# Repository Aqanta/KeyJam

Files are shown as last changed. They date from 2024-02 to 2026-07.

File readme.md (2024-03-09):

# Aqanta KeyJam

The Aqanta KeyJam is a powerful opensource macro-pad that can be configured to send HID keystrokes, run complex macros on a connected computer, or be used as a drum-pad. 
The KeyJam runs on an RP2040 (Pico) board and can use a companion Electron app for control.

All code, designs, and methodology can be found in this repo. The project is unfinished and will be updated over time.

## Drums on Alpine Linux

APK installs:

fluidsynth

fluidsynth python driver is here, needs to be installed manually

https://github.com/nwhitehead/pyfluidsynth

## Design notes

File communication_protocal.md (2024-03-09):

## Serial Communication Protocol

This page describes how communication between the control app (Electron) and the KeyJam (RP2040 microcontroller) works.
All communication is done over the USB serial port and is primarily for setting key mappings.

>All serial commands are sent as text strings. No upper character limit has been observed.

### Definitions
* Keymapping
  * A map of what keys on the macropad press what keyboard keys or trigger macros
  * i.e. key 26 presses 'CONTROL + V'
* Profile
  * Set of keymappings
  * There are two levels of profiles, base and app
* Base Profile
  * This profile has mappings for all keys
  * One (and only one) must be applied at all times
* App Profile
  * Has mappings for some, but not all keys
  * Overrides base profile (where there is overlap)
  * Support for only 1 applied at a time (could be increased later)
* Keystroke
  * KeyJam sending an HID keyboard data stating a key is pressed
  * Three basic types: printing/non-printing, modifier, & consumer
  * Can be held down or pressed and released immediately
* Macro
  * A command to do something other than a keystroke
  * Almost always handled by the control software on the computer
  * i.e. key 13 sends a GET request to a URL

### Purposes & Functions
##### App to Device
* Set a keymapping (edit profile)
  * Per profile
  * Can be a keystroke or macro
* Create a profile
* Switch base profile
* Switch app profile
* Request profile data
##### Device to App
* Trigger macro

>These only take keystrokes into consideration. If built in, RGB lights will be controlled similarly

### Protocol
* All messages end with `\r\n`
  * A message is incrementally stored and not processed until `\r\n` is read
* Messages are send in a command line style, with parameters seperated by spaces and options set by flags
  * `list -c y -p base` tells the KeyJam to send the current base profile over serial
* Most responses to commands are given in JSON
#### Message structure
* Commands
  * Commands signify what action is to be taken. The following is an exhaustive list of commands:
  * App to Device
    * `update` - Updates a keymapping
    * `create` - Creates a new profile (non-destructive)
    * `list` - Returns a list of saved profiles, or the contents of a specified profile
  * Device to App
    * `press` - A macro key was pressed
* Flags
  * Flags are common across commands, though not every flag can be used in every command
    * `-p` - an profile (by id)
    * `-pt` - specifies profile type (can be `base` or `app`)
    * `-i` - the input number
    * `-j` - A JSON object (usually a key profile)
    * ~~`-it` - input type (`button`, `rotary`, etc.)~~

### Key JSON Format

```json
{
  "macro": false,
  "keys": ["a", 128],
  "consumerKey": 205,
  "hold": false
}
```

The `macro` boolean tells the controller if it should send the key press over the serial port.

The `keys` array lists all the keys that will send over via HID to the computer

The `consumerKey` integer contains a keycode for a consumer key

The `hold` boolean controls whether the keys are 'held down' or quickly presses and released.

All fields are optional, but it is encouraged to put a false value if there is no action to be taken.

### Profile JSON format

Each profile is an object with the following properties:

````json
{
  "id": "default",
  "displayName": "Default",
  "buttons": [],
  "rotaryEncoders": [],
  "potentiometers": []
}
````
Each button, rotary encoder, & potentiometer has a zero-based index associated with it. Each category has a list with a key (or key like object) in it.

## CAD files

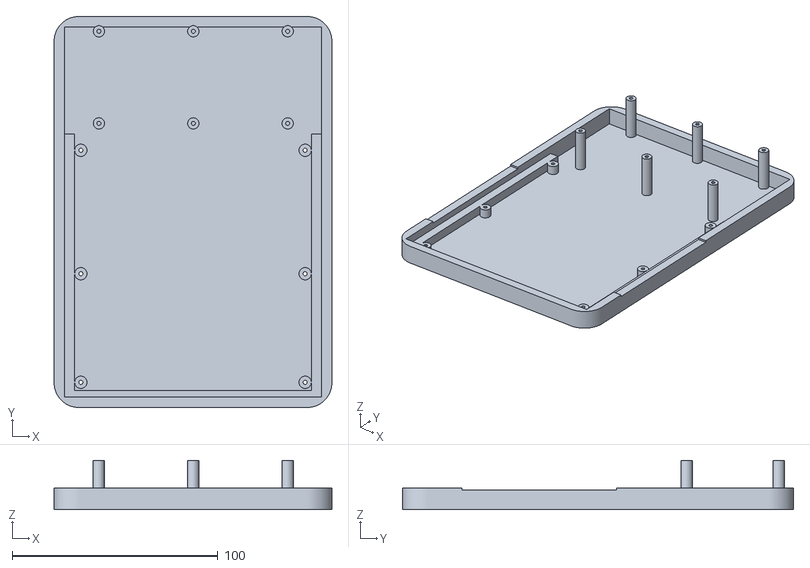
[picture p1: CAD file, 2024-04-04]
Design/3D Models/Frames/KeyJam Max Bottom.stl
135.0 x 190.0 x 24.0

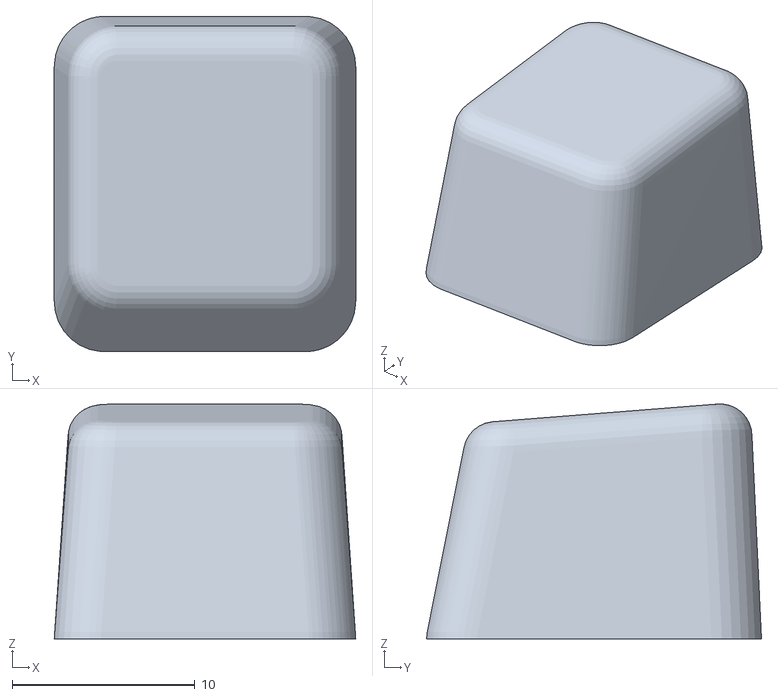
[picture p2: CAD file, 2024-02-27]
Design/3D Models/Keycap Prototypes/rounded_square_tall.stl
16.5 x 18.3 x 12.8

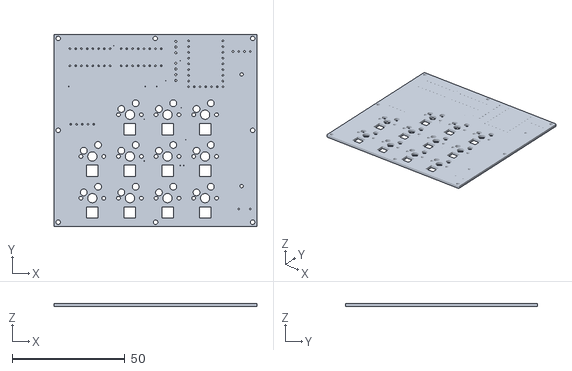
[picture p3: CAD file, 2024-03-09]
Design/3D Models/KeyJam PCB.stl
90.0 x 85.0 x 1.50

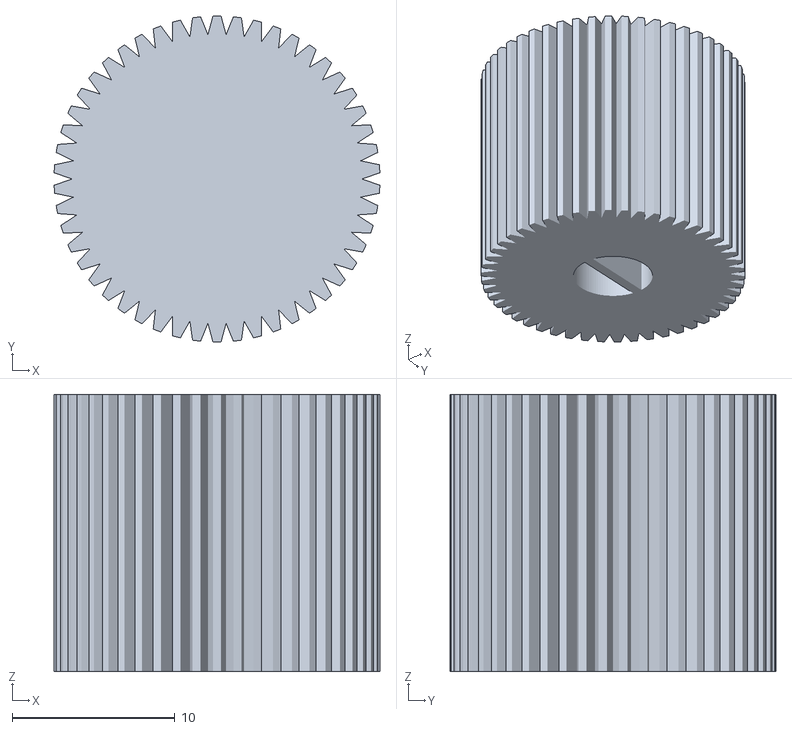
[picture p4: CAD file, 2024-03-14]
Design/3D Models/Knobs/Knob #1.stl
20.0 x 20.0 x 17.0

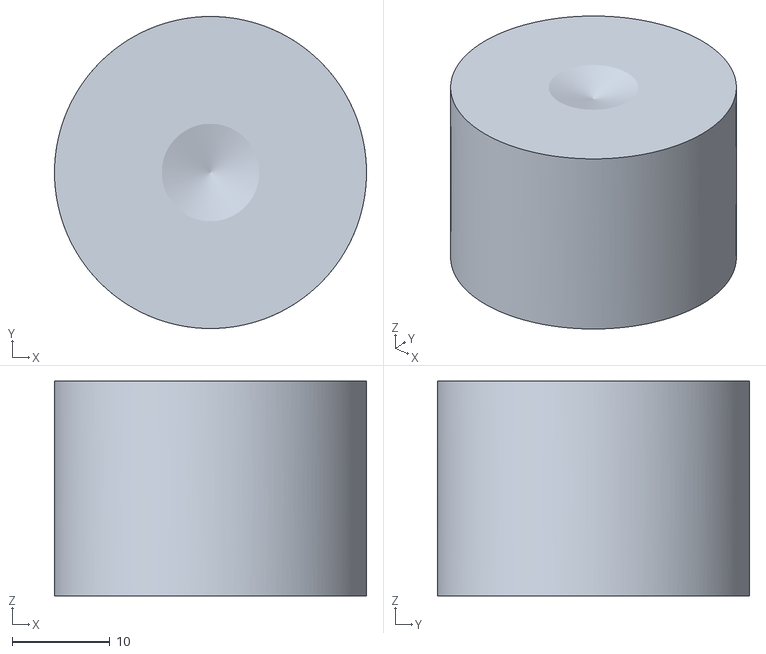
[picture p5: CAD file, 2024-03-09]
Design/3D Models/Knobs/v1/Knob #1.stl
32.0 x 32.0 x 22.0

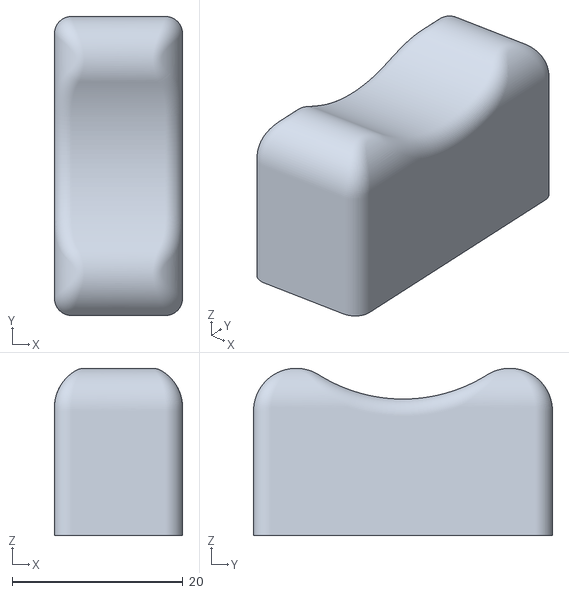
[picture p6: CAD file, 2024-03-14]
Design/3D Models/Sliders/Slider #3.stl
15.0 x 35.0 x 19.6

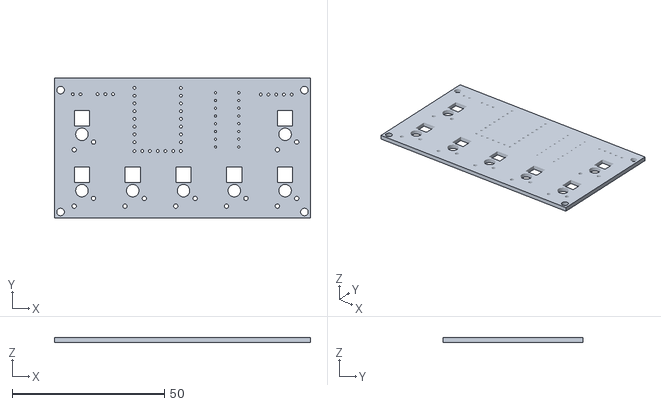
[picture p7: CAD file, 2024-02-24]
Design/3D Models/7 Key Prototype.stl
84.0 x 46.0 x 1.50

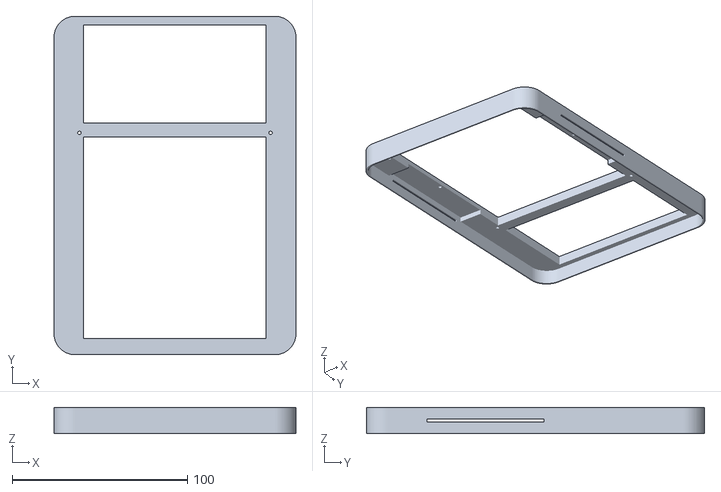
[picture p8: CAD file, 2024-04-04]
Design/3D Models/Frames/KeyJam Max Top.stl
138.0 x 193.0 x 15.0

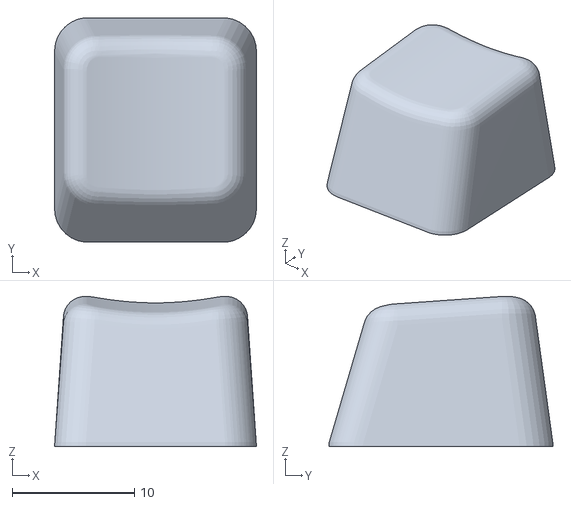
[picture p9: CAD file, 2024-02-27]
Design/3D Models/Keycap Prototypes/rounded_square_cylindrical.stl
16.5 x 18.3 x 12.3

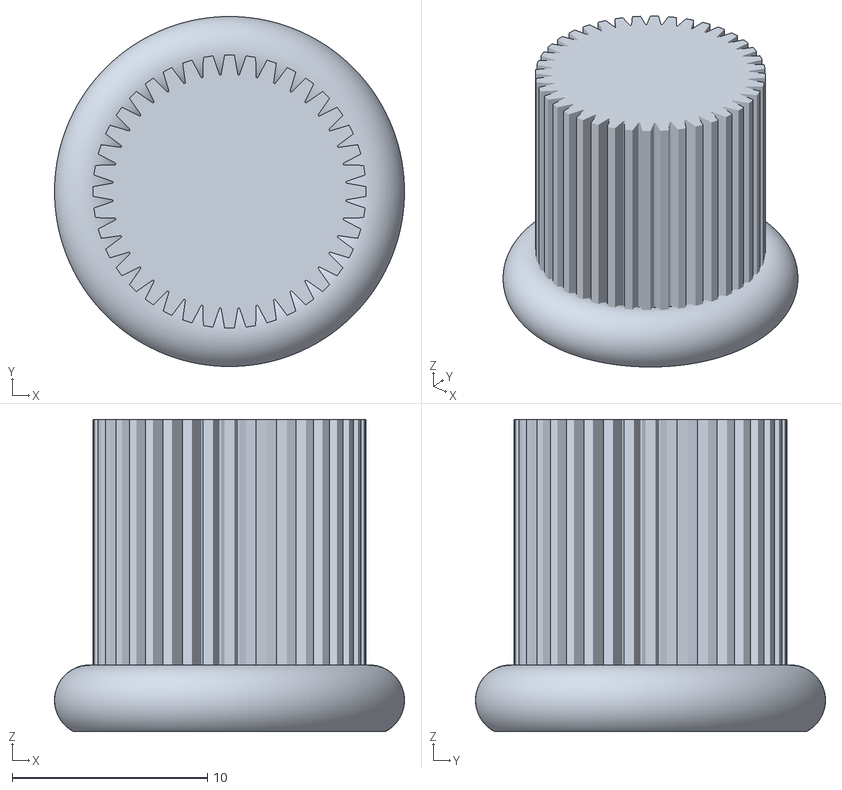
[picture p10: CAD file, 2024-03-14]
Design/3D Models/Knobs/Knob #5.stl
17.9 x 17.9 x 16.0

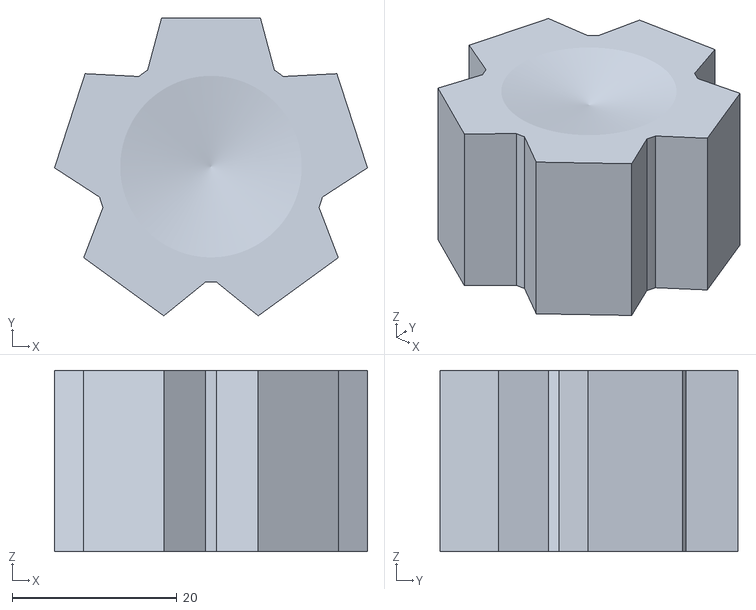
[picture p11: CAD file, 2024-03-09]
Design/3D Models/Knobs/v1/Knob #5.stl
37.9 x 36.1 x 22.0

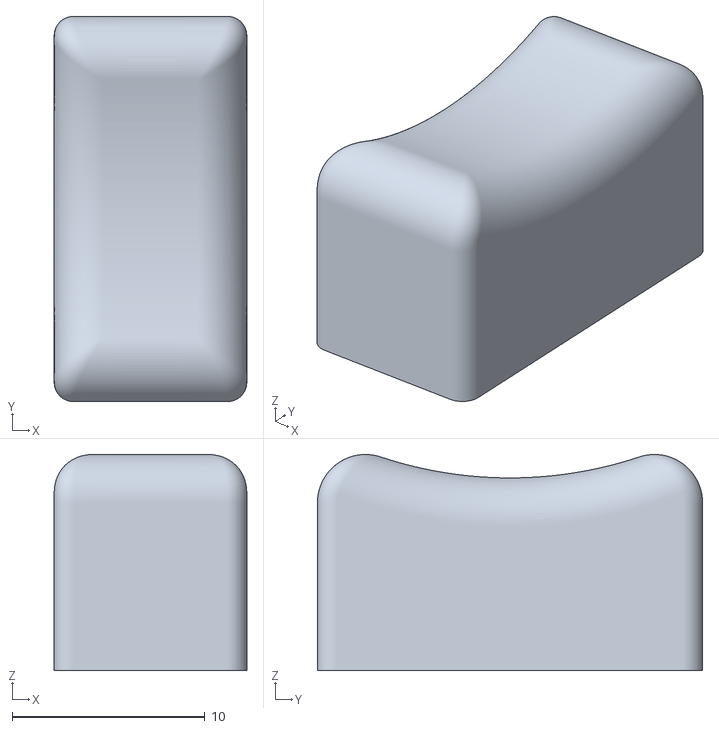
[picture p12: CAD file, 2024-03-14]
Design/3D Models/Sliders/Slider #2.stl
10.0 x 20.0 x 11.2

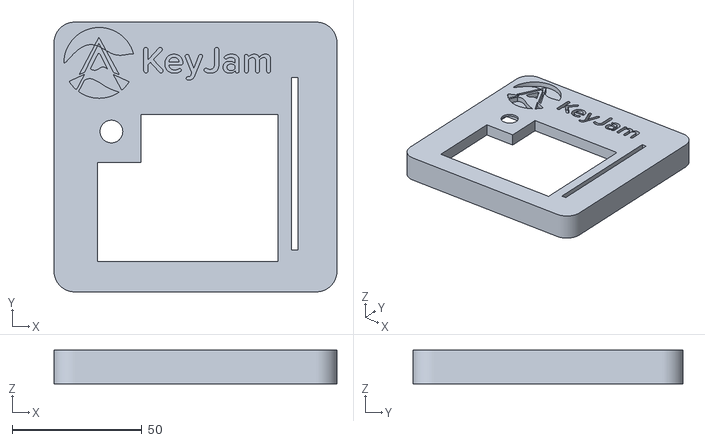
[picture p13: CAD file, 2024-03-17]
Design/3D Models/Frames/KeyJam Top.stl
109.1 x 104.0 x 13.0

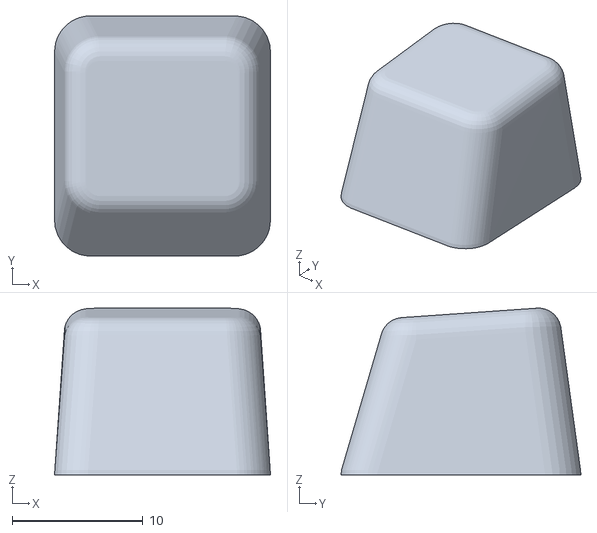
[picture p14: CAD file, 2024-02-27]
Design/3D Models/Keycap Prototypes/rounded_square.stl
16.5 x 18.3 x 12.7

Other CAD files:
Design/3D Models/Knobs/Knob #6.stl
Design/3D Models/Knobs/v1/Knob #6.stl
Design/3D Models/Sliders/Slider #1.stl
Design/3D Models/Frames/KeyJam Bottom.stl
Design/3D Models/Frames/KeyJam Housing.f3d
Design/3D Models/Frames/KeyJam Key Frame.stl
Design/3D Models/Frames/KeyJam Max Frame.stl
Design/3D Models/Frames/KeyJam Max Tippity-Top.stl
Design/3D Models/Keycap Prototypes/dsa_key.stl
Design/3D Models/Keycap Prototypes/flat_square.stl
Design/3D Models/Keycap Prototypes/g20_key.stl
Design/3D Models/Keycap Prototypes/square_dish.stl
Design/3D Models/Keycap Prototypes/square_key.stl
Design/3D Models/Knobs/Knob #2.stl
Design/3D Models/Knobs/Knob #3.stl
Design/3D Models/Knobs/Knob #4.stl
Design/3D Models/Knobs/v1/Knob #2.stl
Design/3D Models/Knobs/v1/Knob #3.stl
Design/3D Models/Knobs/v1/Knob #4.stl

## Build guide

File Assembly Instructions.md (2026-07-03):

# KeyJam Assembly Instructions

## Parts

### PCB

* KeyJam PCB
* 11x 10kΩ 1206 SMD Resistors
* 11x MK hotswap SMD sockets
* RP2040 Zero (with headers)
* 2x SN74HC165N shift registers
* 5 pin rotary encoder
* 10k linear potentiometer

### Case

* 3D printed parts:
  * Case bottom
  * Case frame/middle
  * Case top
  * 11x keycaps
  * Rotary encoder cap
  * Slider cap
* 11x MX switches
* 4x m2x16 screws
* 4x Clear self-adhesive rubber feet

## Assembly

### PCB - Bottom Side

The first step is to solder the SMD components on the bottom of the board. **Using a heat gun or hot plate is highly recommended for this step.** You will need the 11 smd resistors, and 11 hotswap sockets. 

Place solder on all the flat SMD (no holes in them) pads on the back of the PCB (the side that says "KeyJam" with the big logo on it). Place the 11 resistors in a line near the top, and insert the hotswap sockets into the holes. Make sure both metal tabs are over the SMD pads, and that they poke through the holes. Then use the heatgun or hotplate to solder. 

Double check all the joins to make sure they are flat and have contact with the metal.

*You can solder the hotpads conventionally, but start with SMD. Add more wire solder as needed if they fall out*

### PCB - Top Side

Place the rest of the components on the PCB:

* The RP2040 Zero goes above the RP2040 logo
* The SN74HC165Ns go in the SR_1 and SR_2 spots, make sure to match the notch
* The slider/potentiometer holes are off center, you will need to bend the pins to fit it in.
* Place the frame over the top of the PCB, then solder the rotary encoder in.

> I recommend using a wedge tip and 0.6mm 60/40 tin/lead solder

### Case

1. Place the PCB (with frame) into the bottom of the case, it should slot in
2. Place the top on
3. Use at least 4 screws in the screw holes at the bottom of the case to screw the stack together.
4. Place the MX switched into the frame
5. Place the keycaps and handles.

## Programming

Clone the git repo and use PlatformIO to flash.

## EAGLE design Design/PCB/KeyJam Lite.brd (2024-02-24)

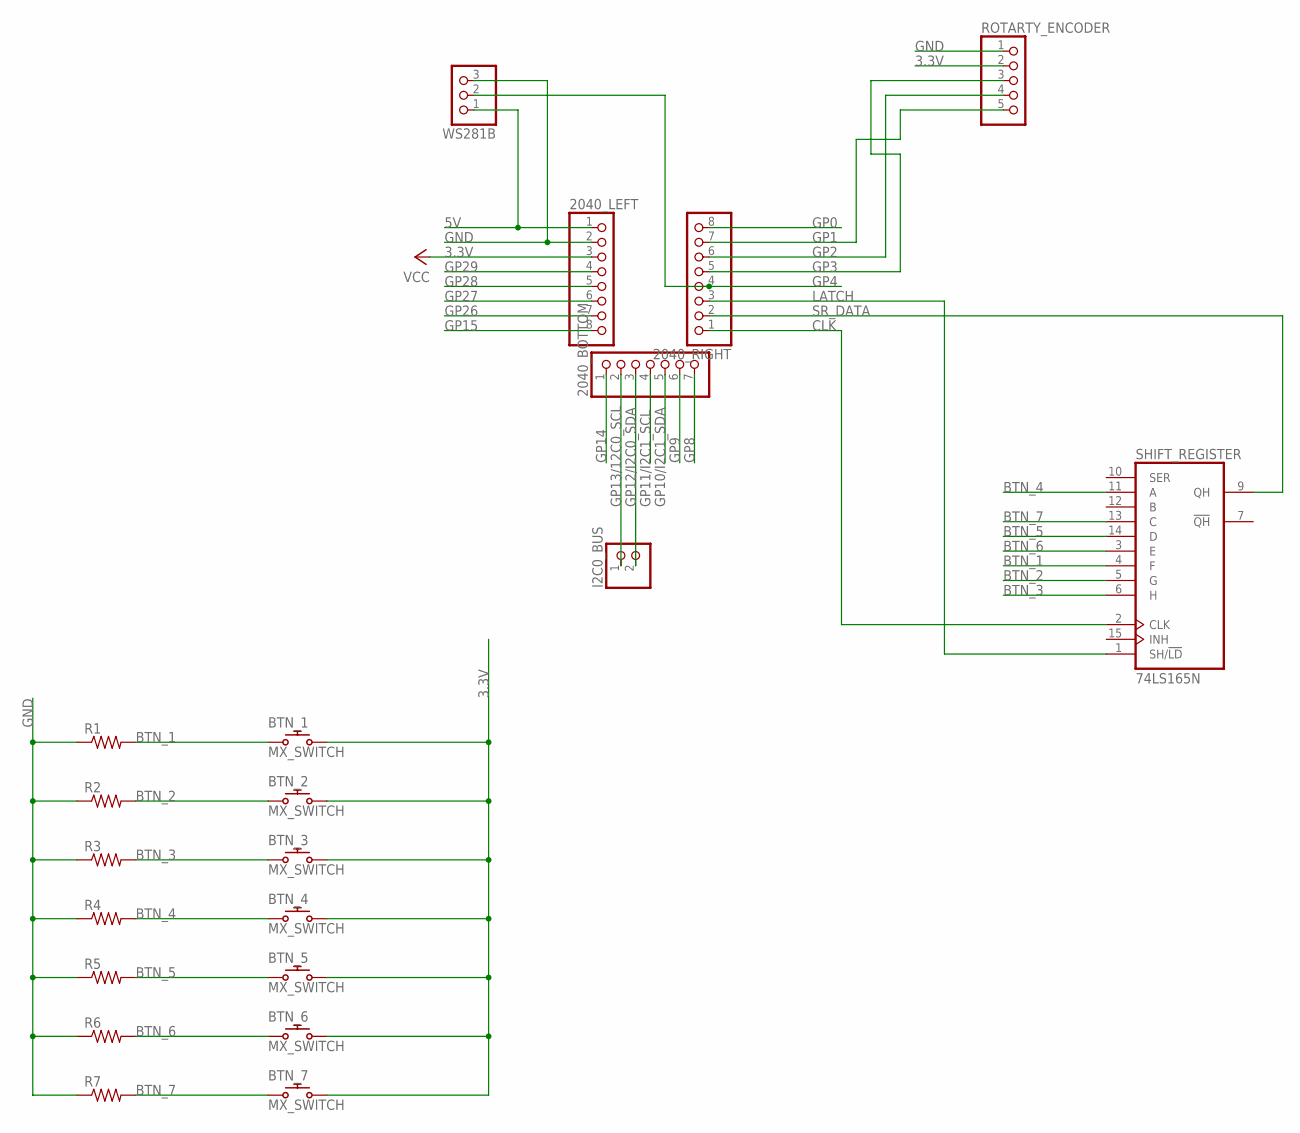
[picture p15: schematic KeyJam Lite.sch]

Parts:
2040_BOTTOM: PINHD-1X7; 1X07
2040_LEFT, 2040_RIGHT: PINHD-1X8; 1X08
BTN_1, BTN_2, BTN_3, BTN_4, BTN_5, BTN_6, BTN_7: MX_SWITCH
I2C0_BUS: PINHD-1X2; 1X02
R1, R2, R3, R4, R5, R6, R7: ADAFRUIT_R-US_R0805; ADAFRUIT_R0805
ROTARTY_ENCODER: PINHD-1X5; 1X05
SHIFT_REGISTER: 74LS165N; DIL16
WS281B: PINHD-1X3; 1X03

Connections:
3.3V: 2040_LEFT.3, BTN_1.S2 (2), BTN_2.S2 (2), BTN_3.S2 (2), BTN_4.S2 (2), BTN_5.S2 (2), BTN_6.S2 (2), BTN_7.S2 (2), ROTARTY_ENCODER.2, SHIFT_REGISTER.16 (VCC)
5V: 2040_LEFT.1, WS281B.1
BTN_1: BTN_1.S1 (1), R1.2, SHIFT_REGISTER.4 (F)
BTN_2: BTN_2.S1 (1), R2.2, SHIFT_REGISTER.5 (G)
BTN_3: BTN_3.S1 (1), R3.2, SHIFT_REGISTER.6 (H)
BTN_4: BTN_4.S1 (1), R4.2, SHIFT_REGISTER.11 (A)
BTN_5: BTN_5.S1 (1), R5.2, SHIFT_REGISTER.14 (D)
BTN_6: BTN_6.S1 (1), R6.2, SHIFT_REGISTER.3 (E)
BTN_7: BTN_7.S1 (1), R7.2, SHIFT_REGISTER.13 (C)
CLK: 2040_RIGHT.1, SHIFT_REGISTER.2 (CLK)
GND: 2040_LEFT.2, R1.1, R2.1, R3.1, R4.1, R5.1, R6.1, R7.1, ROTARTY_ENCODER.1, SHIFT_REGISTER.8 (GND), WS281B.3
GP0: 2040_RIGHT.8
GP1: 2040_RIGHT.7, ROTARTY_ENCODER.5
GP2: 2040_RIGHT.6, ROTARTY_ENCODER.4
GP3: 2040_RIGHT.5, ROTARTY_ENCODER.3
GP4: 2040_RIGHT.4, WS281B.2
GP8: 2040_BOTTOM.7
GP9: 2040_BOTTOM.6
GP10/I2C1_SDA: 2040_BOTTOM.5
GP11/I2C1_SCL: 2040_BOTTOM.4
GP12/I2C0_SDA: 2040_BOTTOM.3, I2C0_BUS.2
GP13/12C0_SCL: 2040_BOTTOM.2, I2C0_BUS.1
GP14: 2040_BOTTOM.1
GP15: 2040_LEFT.8
GP26: 2040_LEFT.7
GP27: 2040_LEFT.6
GP28: 2040_LEFT.5
GP29: 2040_LEFT.4
LATCH: 2040_RIGHT.3, SHIFT_REGISTER.1 (SH/!LD)
SR_DATA: 2040_RIGHT.2, SHIFT_REGISTER.9 (QH)

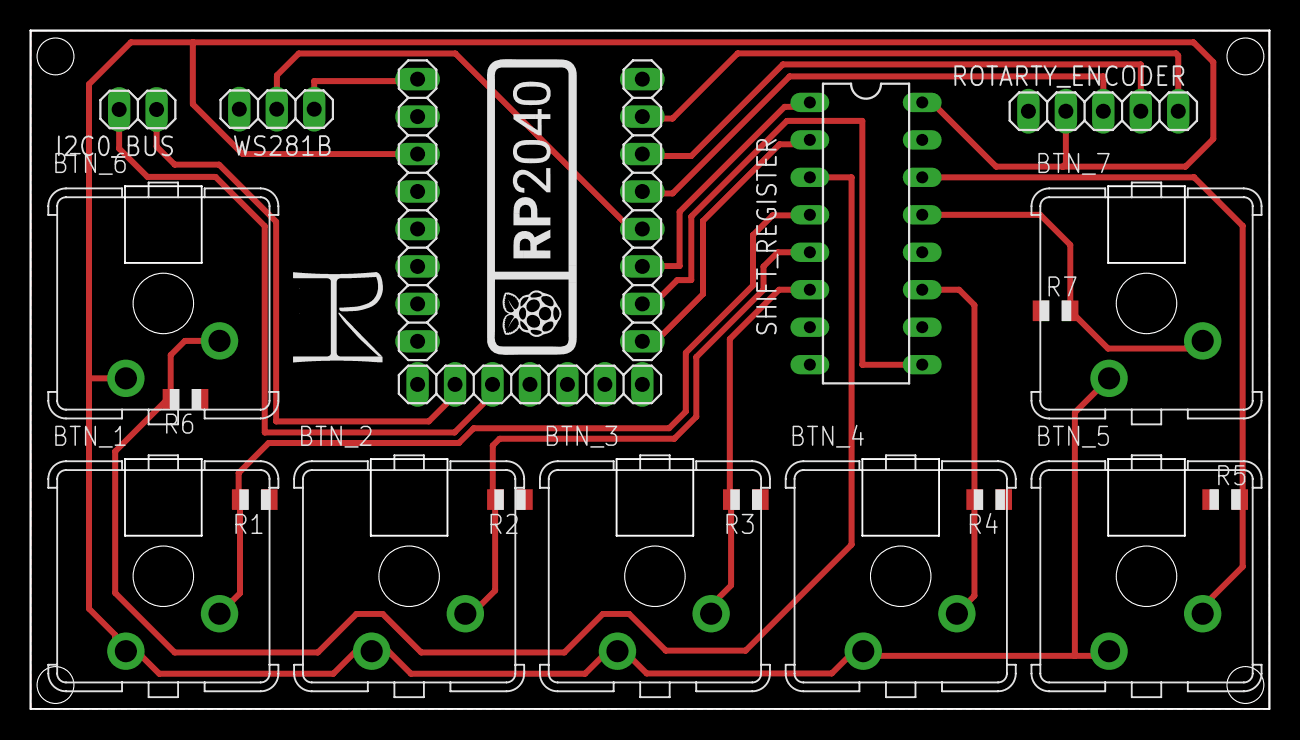
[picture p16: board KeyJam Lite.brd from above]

Board: 2 copper layers, 84.0 x 46.0 mm, 22 parts (0 on the bottom side), 19 nets.

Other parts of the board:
U$1: RASPI_RP2040_LOGO_20MM

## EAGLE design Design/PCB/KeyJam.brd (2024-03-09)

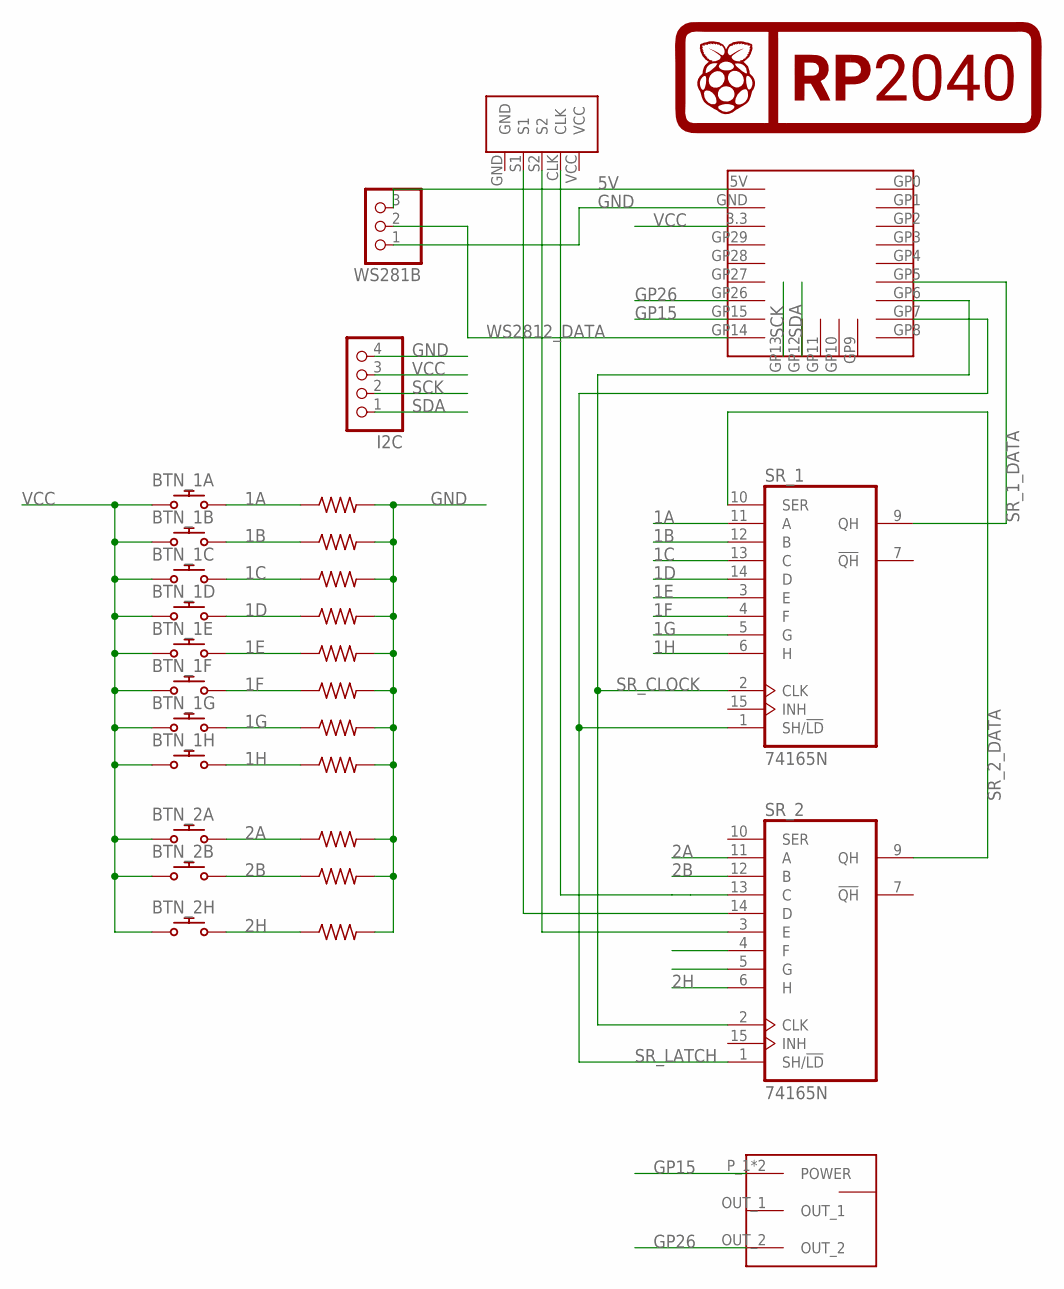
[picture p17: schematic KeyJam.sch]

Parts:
BTN_1A, BTN_1B, BTN_1C, BTN_1D, BTN_1E, BTN_1F, BTN_1G, BTN_1H, BTN_2A, BTN_2B, BTN_2H: MX_SWITCH
I2C: PINHD-1X4; 1X04
R1, R2, R3, R4, R5, R6, R7, R8, R9, R10, R11: R-US_R1206; R1206
SLIDER: SLIDER
SR_1, SR_2: 74165N; DIL16
U$1: RP2040-ZERO
U$2: ROUND_ROTARY
U$3: RASPI_RP2040_LOGO_20MM
WS281B: PINHD-1X3; 1X03

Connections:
1A: BTN_1A.$2 (2), R1.1, SR_1.11 (A)
1B: BTN_1B.$2 (2), R2.1, SR_1.12 (B)
1C: BTN_1C.$2 (2), R3.1, SR_1.13 (C)
1D: BTN_1D.$2 (2), R4.1, SR_1.14 (D)
1E: BTN_1E.$2 (2), R5.1, SR_1.3 (E)
1F: BTN_1F.$2 (2), R6.1, SR_1.4 (F)
1G: BTN_1G.$2 (2), R7.1, SR_1.5 (G)
1H: BTN_1H.$2 (2), R8.1, SR_1.6 (H)
2A: BTN_2A.$2 (2), R9.1, SR_2.11 (A)
2B: BTN_2B.$2 (2), R10.1, SR_2.12 (B)
2H: BTN_2H.$2 (2), R11.1, SR_2.6 (H)
5V: U$1.5V (5), WS281B.3
GND: I2C.4, R1.2, R2.2, R3.2, R4.2, R5.2, R6.2, R7.2, R8.2, R9.2, R10.2, R11.2, SLIDER.GND_1 (GND), SLIDER.GND_2 (GND), SR_1.8 (GND), SR_2.8 (GND), U$1.GND, U$2.GND, WS281B.1
GP15: SLIDER.P_1 (POWER), SLIDER.P_2 (POWER), U$1.GP15
GP26: SLIDER.OUT_2, U$1.GP26
unnamed: SR_2.13 (C), U$2.CLK
unnamed: SR_2.14 (D), U$2.S1
unnamed: SR_2.3 (E), U$2.S2
SCK: I2C.2, U$1.GP13
SDA: I2C.1, U$1.GP12
SR_1_DATA: SR_1.9 (QH), U$1.GP5
SR_2_DATA: SR_1.10 (SER), SR_2.9 (QH)
SR_CLOCK: SR_1.2 (CLK), SR_2.2 (CLK), U$1.GP6
SR_LATCH: SR_1.1 (SH/!LD), SR_2.1 (SH/!LD), U$1.GP7
VCC: BTN_1A.$1 (1), BTN_1B.$1 (1), BTN_1C.$1 (1), BTN_1D.$1 (1), BTN_1E.$1 (1), BTN_1F.$1 (1), BTN_1G.$1 (1), BTN_1H.$1 (1), BTN_2A.$1 (1), BTN_2B.$1 (1), BTN_2H.$1 (1), I2C.3, SR_1.16 (VCC), SR_2.16 (VCC), U$1.3.3, U$2.VCC
WS2812_DATA: U$1.GP14, WS281B.2

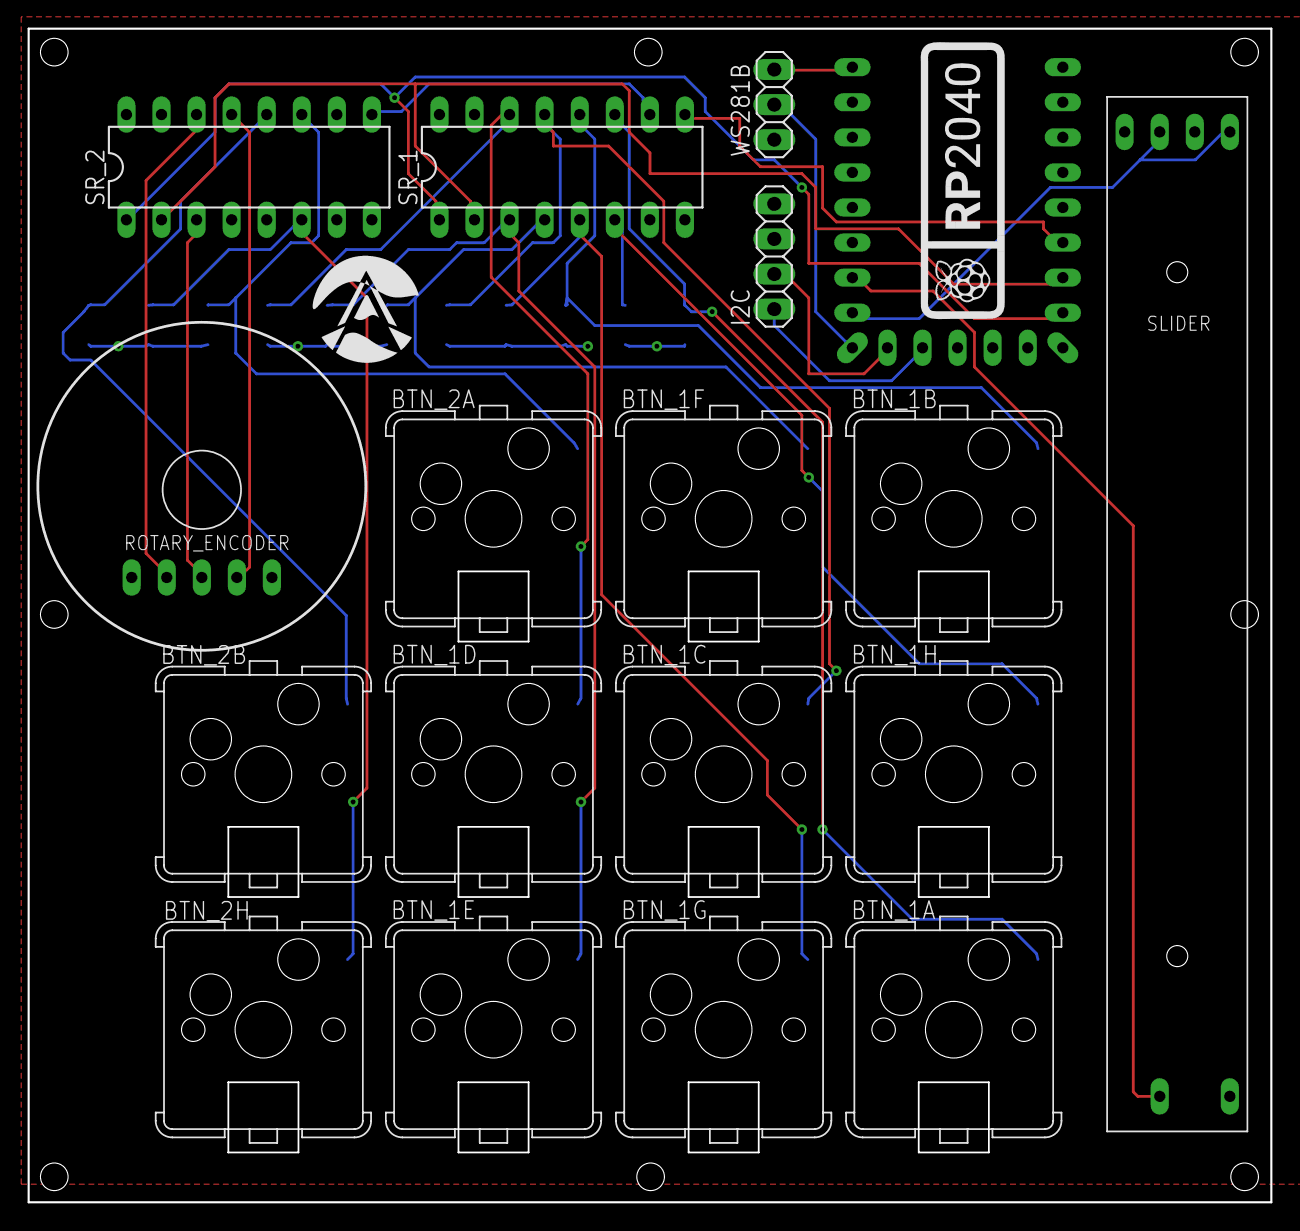
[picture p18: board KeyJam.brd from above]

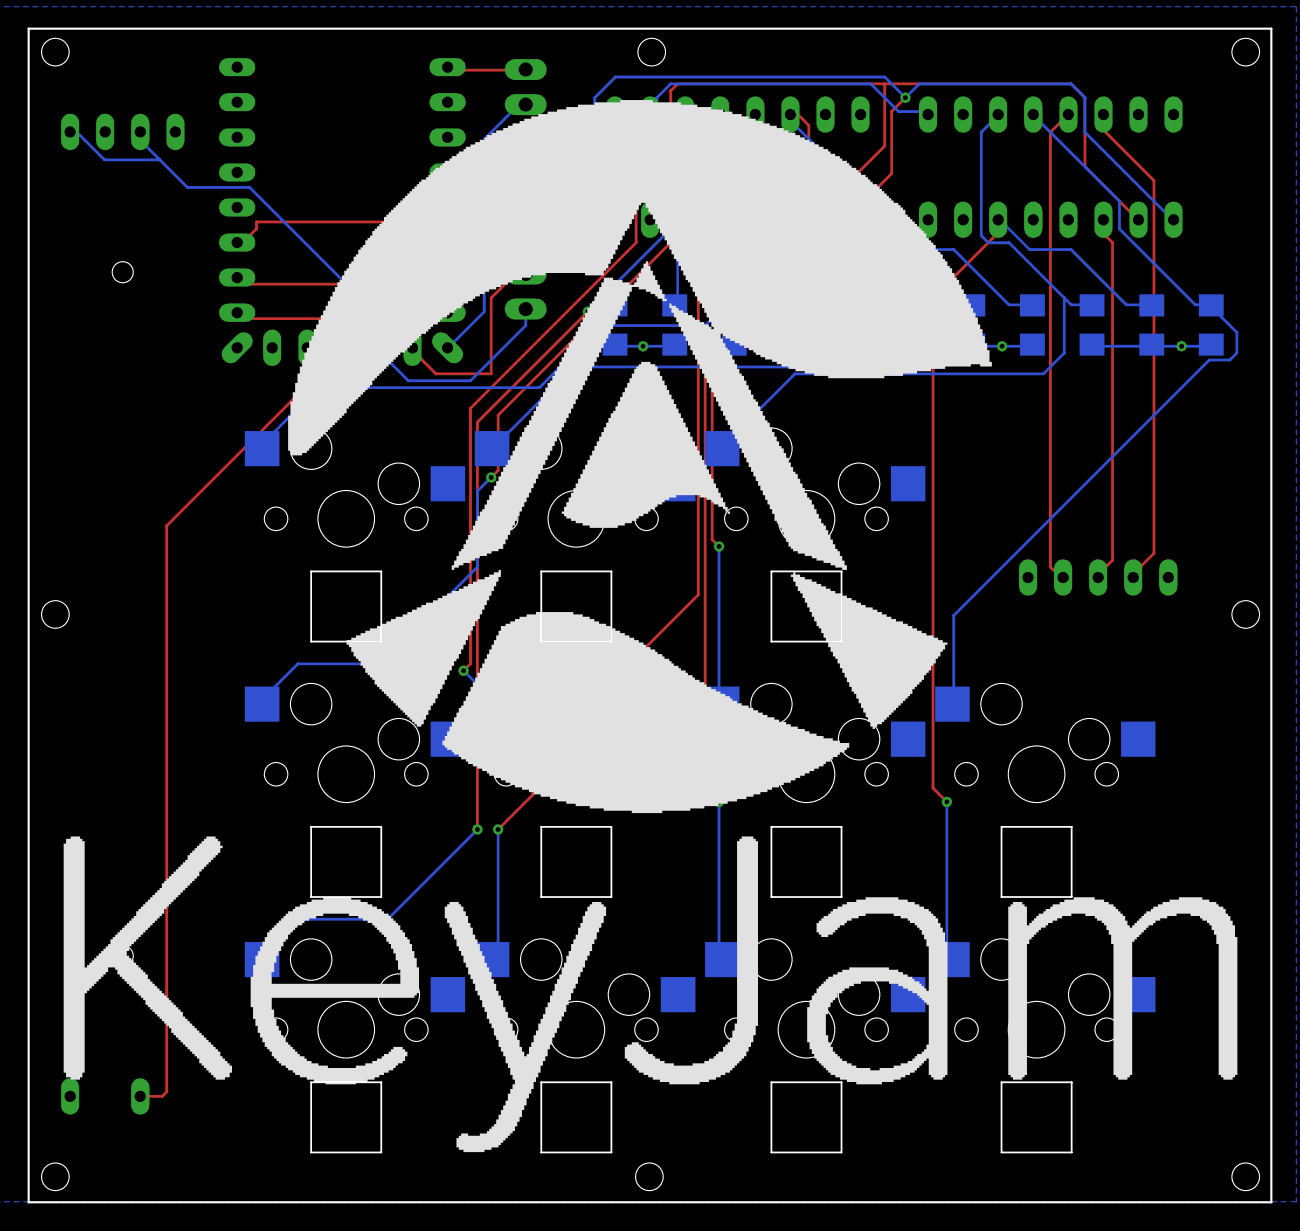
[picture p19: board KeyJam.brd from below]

Board: 2 copper layers, 90.0 x 85.0 mm, 30 parts (11 on the bottom side), 26 nets.

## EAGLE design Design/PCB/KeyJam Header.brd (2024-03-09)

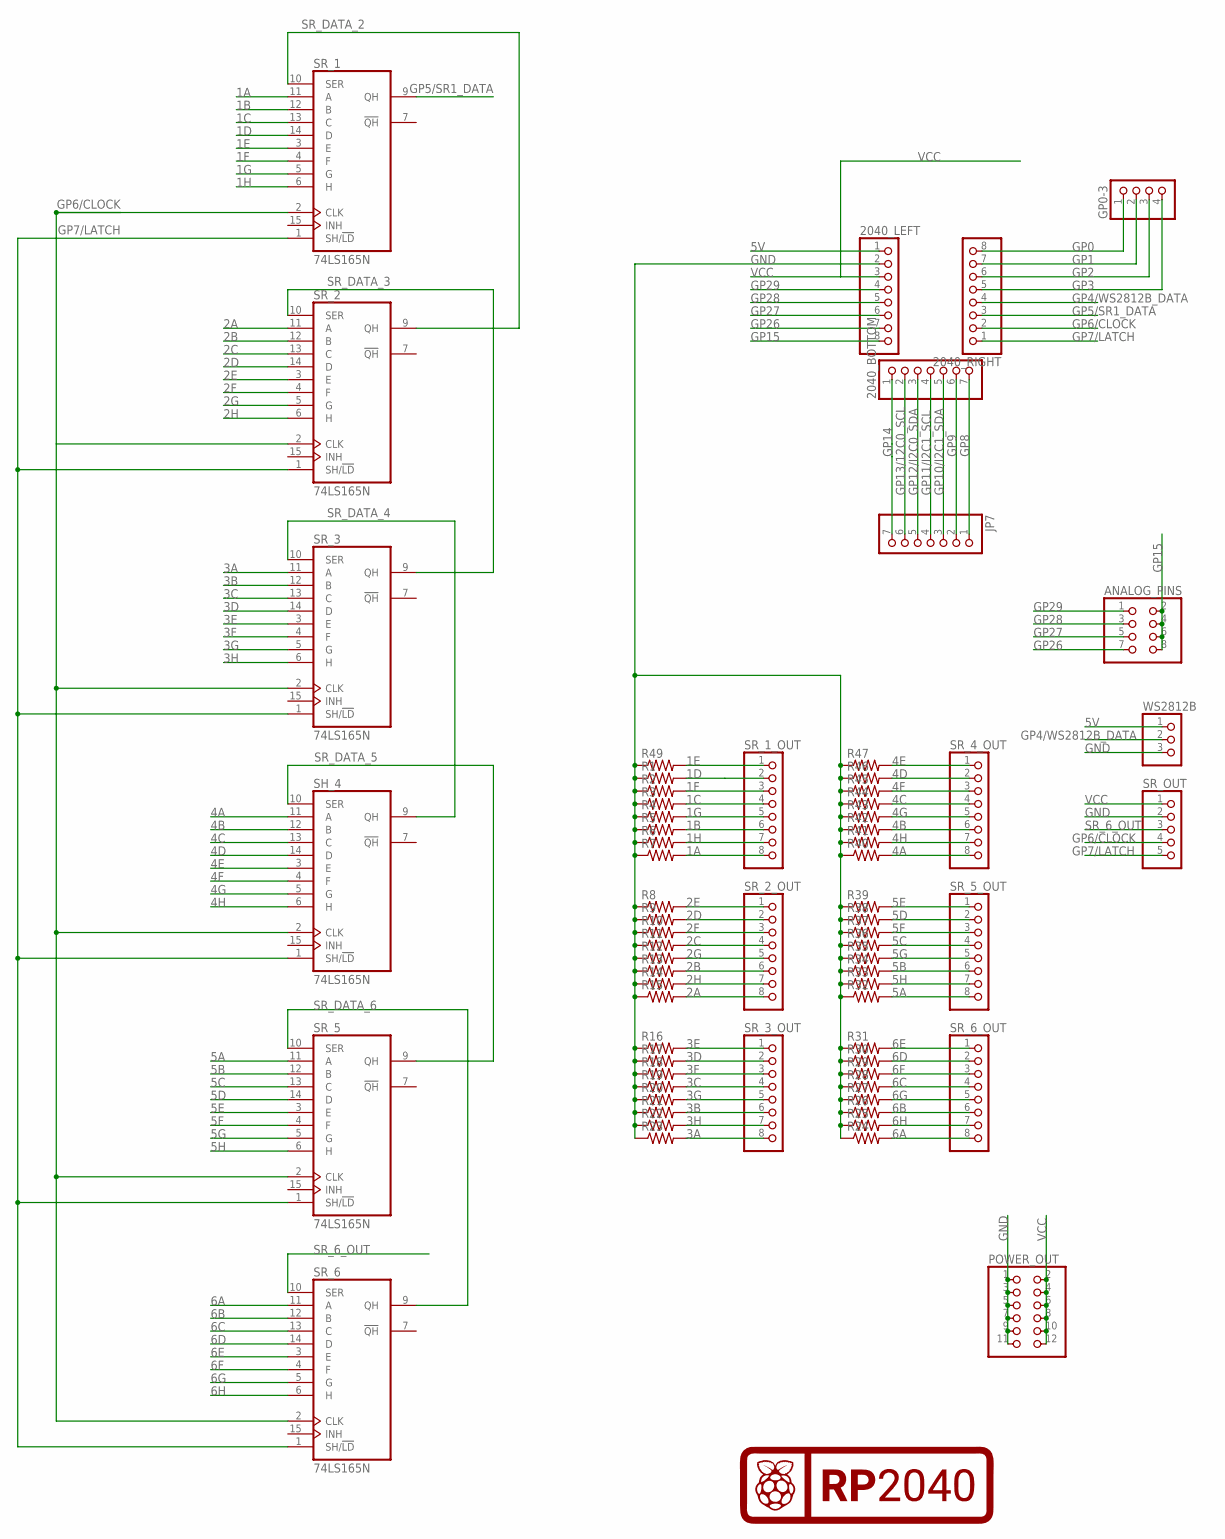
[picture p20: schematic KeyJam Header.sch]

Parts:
2040_BOTTOM: PINHD-1X7; 1X07
2040_LEFT, 2040_RIGHT: PINHD-1X8; 1X08
ANALOG_PINS: PINHD-2X4; 2X04
GP0-3: PINHD-1X4; 1X04
JP7: PINHD-1X7; 1X07
POWER_OUT: PINHD-2X6; 2X06
R1, R2, R3, R4, R5, R6, R7, R8, R9, R10, R11, R12, R13, R14, R15, R16, R17, R18, R19, R20, R21, R22, R23, R24, R25, R26, R27, R28, R29, R30, R31, R32, R33, R34, R35, R36, R37, R38, R39, R40, R41, R42, R43, R44, R45, R46, R47, R49: R-US_R1206; R1206
SH_4: 74LS165N; DIL16
SR_1, SR_2, SR_3, SR_5, SR_6: 74LS165N; DIL16
SR_1_OUT, SR_2_OUT, SR_3_OUT, SR_4_OUT, SR_5_OUT, SR_6_OUT: PINHD-1X8; 1X08
SR_OUT: PINHD-1X5; 1X05
U$1: RASPI_RP2040_LOGO_20MM
WS2812B: PINHD-1X3; 1X03

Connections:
1A: R7.2, SR_1.11 (A), SR_1_OUT.8
1B: R5.2, SR_1.12 (B), SR_1_OUT.6
1C: R3.2, SR_1.13 (C), SR_1_OUT.4
1D: R1.2, SR_1.14 (D), SR_1_OUT.2
1E: R49.2, SR_1.3 (E), SR_1_OUT.1
1F: R2.2, SR_1.4 (F), SR_1_OUT.3
1G: R4.2, SR_1.5 (G), SR_1_OUT.5
1H: R6.2, SR_1.6 (H), SR_1_OUT.7
2A: R15.2, SR_2.11 (A), SR_2_OUT.8
2B: R13.2, SR_2.12 (B), SR_2_OUT.6
2C: R11.2, SR_2.13 (C), SR_2_OUT.4
2D: R9.2, SR_2.14 (D), SR_2_OUT.2
2E: R8.2, SR_2.3 (E), SR_2_OUT.1
2F: R10.2, SR_2.4 (F), SR_2_OUT.3
2G: R12.2, SR_2.5 (G), SR_2_OUT.5
2H: R14.2, SR_2.6 (H), SR_2_OUT.7
3A: R23.2, SR_3.11 (A), SR_3_OUT.8
3B: R21.2, SR_3.12 (B), SR_3_OUT.6
3C: R19.2, SR_3.13 (C), SR_3_OUT.4
3D: R17.2, SR_3.14 (D), SR_3_OUT.2
3E: R16.2, SR_3.3 (E), SR_3_OUT.1
3F: R18.2, SR_3.4 (F), SR_3_OUT.3
3G: R20.2, SR_3.5 (G), SR_3_OUT.5
3H: R22.2, SR_3.6 (H), SR_3_OUT.7
4A: R40.2, SH_4.11 (A), SR_4_OUT.8
4B: R42.2, SH_4.12 (B), SR_4_OUT.6
4C: R44.2, SH_4.13 (C), SR_4_OUT.4
4D: R46.2, SH_4.14 (D), SR_4_OUT.2
4E: R47.2, SH_4.3 (E), SR_4_OUT.1
4F: R45.2, SH_4.4 (F), SR_4_OUT.3
4G: R43.2, SH_4.5 (G), SR_4_OUT.5
4H: R41.2, SH_4.6 (H), SR_4_OUT.7
5A: R32.2, SR_5.11 (A), SR_5_OUT.8
5B: R34.2, SR_5.12 (B), SR_5_OUT.6
5C: R36.2, SR_5.13 (C), SR_5_OUT.4
5D: R38.2, SR_5.14 (D), SR_5_OUT.2
5E: R39.2, SR_5.3 (E), SR_5_OUT.1
5F: R37.2, SR_5.4 (F), SR_5_OUT.3
5G: R35.2, SR_5.5 (G), SR_5_OUT.5
5H: R33.2, SR_5.6 (H), SR_5_OUT.7
5V: 2040_LEFT.1, WS2812B.1
6A: R24.2, SR_6.11 (A), SR_6_OUT.8
6B: R26.2, SR_6.12 (B), SR_6_OUT.6
6C: R28.2, SR_6.13 (C), SR_6_OUT.4
6D: R30.2, SR_6.14 (D), SR_6_OUT.2
6E: R31.2, SR_6.3 (E), SR_6_OUT.1
6F: R29.2, SR_6.4 (F), SR_6_OUT.3
6G: R27.2, SR_6.5 (G), SR_6_OUT.5
6H: R25.2, SR_6.6 (H), SR_6_OUT.7
GND: 2040_LEFT.2, POWER_OUT.1, POWER_OUT.3, POWER_OUT.5, POWER_OUT.7, POWER_OUT.9, POWER_OUT.11, R1.1, R2.1, R3.1, R4.1, R5.1, R6.1, R7.1, R8.1, R9.1, R10.1, R11.1, R12.1, R13.1, R14.1, R15.1, R16.1, R17.1, R18.1, R19.1, R20.1, R21.1, R22.1, R23.1, R24.1, R25.1, R26.1, R27.1, R28.1, R29.1, R30.1, R31.1, R32.1, R33.1, R34.1, R35.1, R36.1, R37.1, R38.1, R39.1, R40.1, R41.1, R42.1, R43.1, R44.1, R45.1, R46.1, R47.1, R49.1, SH_4.8 (GND), SR_1.8 (GND), SR_2.8 (GND), SR_3.8 (GND), SR_5.8 (GND), SR_6.8 (GND), SR_OUT.2, WS2812B.3
GP0: 2040_RIGHT.8, GP0-3.1
GP1: 2040_RIGHT.7, GP0-3.2
GP2: 2040_RIGHT.6, GP0-3.3
GP3: 2040_RIGHT.5, GP0-3.4
GP4/WS2812B_DATA: 2040_RIGHT.4, WS2812B.2
GP5/SR1_DATA: 2040_RIGHT.3, SR_1.9 (QH)
GP6/CLOCK: 2040_RIGHT.2, SH_4.2 (CLK), SR_1.2 (CLK), SR_2.2 (CLK), SR_3.2 (CLK), SR_5.2 (CLK), SR_6.2 (CLK), SR_OUT.4
GP7/LATCH: 2040_RIGHT.1, SH_4.1 (SH/!LD), SR_1.1 (SH/!LD), SR_2.1 (SH/!LD), SR_3.1 (SH/!LD), SR_5.1 (SH/!LD), SR_6.1 (SH/!LD), SR_OUT.5
GP8: 2040_BOTTOM.7, JP7.1
GP9: 2040_BOTTOM.6, JP7.2
GP10/I2C1_SDA: 2040_BOTTOM.5, JP7.3
GP11/I2C1_SCL: 2040_BOTTOM.4, JP7.4
GP12/I2C0_SDA: 2040_BOTTOM.3, JP7.5
GP13/12C0_SCL: 2040_BOTTOM.2, JP7.6
GP14: 2040_BOTTOM.1, JP7.7
GP15: 2040_LEFT.8, ANALOG_PINS.2, ANALOG_PINS.4, ANALOG_PINS.6, ANALOG_PINS.8
GP26: 2040_LEFT.7, ANALOG_PINS.7
GP27: 2040_LEFT.6, ANALOG_PINS.5
GP28: 2040_LEFT.5, ANALOG_PINS.3
GP29: 2040_LEFT.4, ANALOG_PINS.1
SR_6_OUT: SR_6.10 (SER), SR_OUT.3
SR_DATA_2: SR_1.10 (SER), SR_2.9 (QH)
SR_DATA_3: SR_2.10 (SER), SR_3.9 (QH)
SR_DATA_4: SH_4.9 (QH), SR_3.10 (SER)
SR_DATA_5: SH_4.10 (SER), SR_5.9 (QH)
SR_DATA_6: SR_5.10 (SER), SR_6.9 (QH)
VCC: 2040_LEFT.3, POWER_OUT.2, POWER_OUT.4, POWER_OUT.6, POWER_OUT.8, POWER_OUT.10, POWER_OUT.12, SH_4.16 (VCC), SR_1.16 (VCC), SR_2.16 (VCC), SR_3.16 (VCC), SR_5.16 (VCC), SR_6.16 (VCC), SR_OUT.1

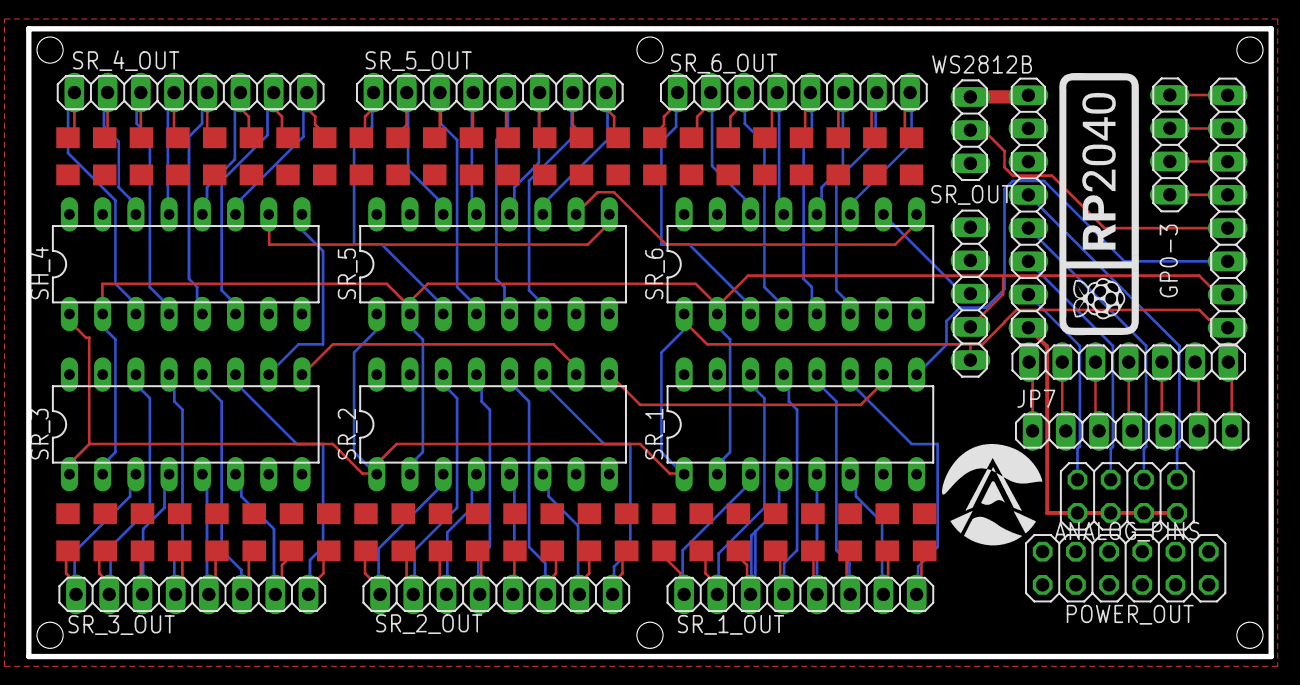
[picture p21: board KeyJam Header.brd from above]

Board: 2 copper layers, 95.0 x 48.0 mm, 70 parts (0 on the bottom side), 77 nets.

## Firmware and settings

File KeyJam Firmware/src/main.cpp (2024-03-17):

#include <Arduino.h>
#include <nlohmann/json.hpp>
#include <Keyboard.h>
#include <LittleFS.h>
#include <sstream>
#include <set>
#include <deque>

//define pins here
#define DATA 5
#define LATCH 7
#define CLOCK 6
//define number of buttons
#define BTN_N 16
//should we re-write the config
#define NEW_CONFIG false

//include other project files
#include "config.h"
#include "serialControl.h"
#include "shiftRegister.h"

//setup json and config
using json = nlohmann::json;
using namespace nlohmann::literals;
json currentBaseConfig;
json currentProfileConfig;

//input/button variables
std::vector<int> inputs( BTN_N );
std::vector<int> rawInputs( BTN_N );
std::vector<int> previousInputs( BTN_N );

//encoder variables
std::set<int> encoderInputs;

//slider variables
std::deque<int> sliderPin1;
std::deque<int> sliderPin2;
int sliderLevel;
int sliderPreviousLevel = -100;

//set up serial
SerialControl serialControl = SerialControl();

//set up shift register
ShiftRegister buttonRegister = ShiftRegister( DATA, CLOCK, LATCH, BTN_N );

//helper function to find the index on a vector
int getIndex( std::vector<std::string> v, const std::string &K ) {
    auto it = find( v.begin(), v.end(), K );
    if ( it != v.end()) {
        return it - v.begin();
    } else {
        return -1;
    }
}

void setup() {
    //If the config file does not exit, create it
    if ( LittleFS.begin() && (!LittleFS.exists( "/config.json" ) || NEW_CONFIG)) {
        initializeConfigFile();
    }

    //load in basic config
    File configFile = LittleFS.open( "/config.json", "r" );
    currentBaseConfig = json::parse( configFile.readString());
    configFile.close();

    //initialize the keyboard
    Keyboard.begin();
}

void loop() {
    //for each input, do the correct action
    for ( int i = 0; i < BTN_N; i++ ) {
        if ( inputs[i] == 1 && previousInputs[i] == 0 ) {
            previousInputs[i] = 1;
            if ( currentBaseConfig["inputs"][i].contains( "macro" ) && currentBaseConfig["inputs"][i]["macro"] ) {
                std::stringstream s;
                s << "press -k " << i;
                SerialControl::send( s.str());
            }
            //consumer keys
            if ( currentBaseConfig["inputs"][i].contains( "consumerKey" ) && currentBaseConfig["inputs"][i]["consumerKey"].is_number()) {
                Keyboard.consumerPress( currentBaseConfig["inputs"][i]["consumerKey"] );
            }
            //all other keys
            if ( currentBaseConfig["inputs"][i].contains( "keys" ) && !currentBaseConfig["inputs"][i]["keys"].empty()) {
                if ( currentBaseConfig["inputs"][i]["keys"].size() > 1 ||
                     (currentBaseConfig["inputs"][i].contains( "hold" ) && currentBaseConfig["inputs"][i]["hold"])) {
                    for ( const auto &j: currentBaseConfig["inputs"][i]["keys"] ) {
                        if ( j.is_number()) {
                            Keyboard.press( j );
                        } else {
                            Keyboard.press(((std::string) j).c_str()[0] );
                        }
                    }
                } else {
                    for ( const auto &j: currentBaseConfig["inputs"][i]["keys"] ) {
                        if ( j.is_number()) {
                            Keyboard.write( j );
                        } else {
                            Keyboard.write(((std::string) j).c_str()[0] );
                        }
                    }
                }
                if ( currentBaseConfig["inputs"][i]["keys"].size() > 1 &&
                     (!currentBaseConfig["inputs"][i].contains( "hold" ) || !currentBaseConfig["inputs"][i]["hold"])) {
                    for ( const auto &j: currentBaseConfig["inputs"][i]["keys"] ) {
                        if ( j.is_number()) {
                            Keyboard.release( j );
                        } else {
                            Keyboard.release(((std::string) j).c_str()[0] );
                        }
                    }
                }
            }
            //if it is an encoder, set the input to zero (encoders don't release)
            if ( encoderInputs.find( i ) != encoderInputs.end()) {
                inputs[i] = 0;
            }
        } else if ( inputs[i] == 0 && previousInputs[i] == 1 ) {
            //release key (if held)
            previousInputs[i] = 0;
            if ( currentBaseConfig["inputs"][i].contains( "hold" ) && currentBaseConfig["inputs"][i]["hold"] ) {
                for ( const auto &j: currentBaseConfig["inputs"][i]["keys"] ) {
                    if ( j.is_number()) {
                        Keyboard.release( j );
                    } else {
                        Keyboard.release(((std::string) j).c_str()[0] );
                    }
                }
            }
            if ( currentBaseConfig["inputs"][i].contains( "consumerKey" ) && currentBaseConfig["inputs"][i]["consumerKey"].is_number()) {
                Keyboard.consumerRelease();
            }
        }

    }

    //send slider updates
    if ( sliderLevel != sliderPreviousLevel ) {
        sliderPreviousLevel = sliderLevel;
        std::stringstream s;
        s << "press -s " << std::to_string( sliderLevel );
        SerialControl::send( s.str());
    }

    //read the serial port
    String msg = serialControl.check();
    if ( msg != "" ) {
        char cmd[32];
        char flag1[4];
        char option1[128];
        char flag2[4];
        char option2[128];
        char flag3[4];
        char option3[128];
        char flag4[4];
        char option4[128];
        int args = std::sscanf( msg.c_str(), "%s -%s %s -%s %s -%s %s -%s %s", cmd, flag1, option1, flag2, option2, flag3, option3, flag4, option4 );
        std::vector<std::string> params = {flag1, option1, flag2, option2, flag3, option3, flag4, option4};
        std::string command = cmd;
        if ( args > 0 && command == "update" ) {
            //TODO check for profiles
            if ( getIndex( params, "i" ) >= 0 ) {
                int inputIndex = 1 + getIndex( params, "i" );
                int valueIndex = 1 + getIndex( params, "j" );
                if ( inputIndex > 0 && valueIndex > 0 ) {
                    currentBaseConfig["inputs"][atoi( params[inputIndex].c_str())] = json::parse( params[valueIndex] );
                    saveConfigFile( currentBaseConfig );
                    SerialControl::send((String) "Updated Input" );
                }
            }
        } else if ( command == "list" ) {
            if ( getIndex( params, "c" ) >= 0 && getIndex( params, "p" ) >= 0 && params[getIndex( params, "p" ) + 1] == "base" ) {
                SerialControl::send( currentBaseConfig.dump());
            } else if ( getIndex( params, "c" ) >= 0 && getIndex( params, "p" ) >= 0 && params[getIndex( params, "p" ) + 1] == "app" ) {
                SerialControl::send( currentProfileConfig.dump());
            } else if ( getIndex( params, "p" ) >= 0 && params[getIndex( params, "p" ) + 1] == "map" ) {
                SerialControl::send( inputMap.dump());
            }
        }
    }

    delay( 10 );
}

std::vector<bool> encoderOn;

void setup1() {
    //sets pin values
    buttonRegister.initialize();
    for ( int i = 0; i < inputMap["encoders"].size(); i++ ) {
        encoderInputs.insert((int) inputMap["encoders"][i]["s1"] );
        encoderInputs.insert((int) inputMap["encoders"][i]["s2"] );
        encoderOn.push_back( false );
    }

    //slider pins
    pinMode( 15, OUTPUT );
    pinMode( 26, INPUT );
    pinMode( 29, INPUT );
}

void loop1() {
    //get inputs from shift register
    buttonRegister.pollRegister( rawInputs );

    for ( int i = 0; i < rawInputs.size(); i++ ) {
        if ( encoderInputs.find( i ) == encoderInputs.end()) {
            inputs[i] = rawInputs[i];
        }
    }

    //read and set encoder state
    for ( int i = 0; i < inputMap["encoders"].size(); i++ ) {
        int s1 = inputMap["encoders"][i]["s1"];
        int s2 = inputMap["encoders"][i]["s2"];
        int clk = inputMap["encoders"][i]["buttonInput"];
        if ( rawInputs[s1] == 0 && rawInputs[s2] == 0 ) {
            inputs[s1] = 0;
            inputs[s2] = 0;
            encoderOn[i] = false;
        } else if ( !encoderOn[i] && rawInputs[s1] == 1 && rawInputs[s2] == 0 ) {
            inputs[s1] = 1;
            inputs[s2] = 0;
            encoderOn[i] = true;
        } else if ( !encoderOn[i] && rawInputs[s1] == 0 && rawInputs[s2] == 1 ) {
            inputs[s1] = 0;
            inputs[s2] = 1;
            encoderOn[i] = true;
        }
        if ( rawInputs[clk] == 0 ) {
            inputs[clk] = 0;
        }
    }

    //get slider level
    digitalWrite( 15, HIGH );
    delayMicroseconds( 1 );

    sliderPin1.push_front( analogRead( 26 ));
    sliderPin2.push_front( analogRead( 29 ));
    digitalWrite( 15, LOW );

    if ( sliderPin1.size() > 50 ) {
        sliderPin1.pop_back();
        sliderPin2.pop_back();
    }

    int pin1avg = 0;
    for ( int t: sliderPin1 ) {
        pin1avg += t;
    }
    pin1avg = pin1avg / sliderPin1.size();


#ifdef TWO_RESISTOR
    int pin2avg = 0;
    for ( int t: sliderPin2 ) {
        pin2avg += t;
    }
    pin2avg = pin2avg / sliderPin2.size();
    sliderLevel = ((int) ((std::log( pin2avg / std::log( 1.005 ))) * 22) - 140) / 5;
     if ( pin1avg < 70 && sliderLevel > 17 ) {
        sliderLevel -= 1;
    }
      if ( pin1avg > 70 ) {
        sliderLevel = 20;
    }
      sliderLevel *= 5;
#else
    sliderLevel = (int) ((std::log( pin1avg ) * 23.63) - 32.769);
#endif
    if ( sliderLevel < 4 ) {
        sliderLevel = 0;
    }
    if(sliderLevel > 96){
        sliderLevel = 100;
    }

    delayMicroseconds( 2 );
}

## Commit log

2024-02-24 Added Prototype Designs
    [7 Key Prototype.brd, 7 Key Prototype.sch, 7 Key Prototype.stl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]
2024-02-27 Updated keycaps
    [rounded_square.stl, rounded_square_concave.stl, rounded_square_cylindrical.stl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]
2024-03-09 Added PCB layouts
    [KeyJam Header.brd, KeyJam Header.sch, KeyJam Lite.brd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]
2024-03-09 Added various 3D Files
    Not all designs are final
    [KeyJam Bottom.stl, KeyJam Housing.f3d, KeyJam Key Frame.stl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]
2024-03-09 Added button layout mapping
2024-03-10 v2 of KeyJam frame
    [KeyJam Bottom.stl, KeyJam Housing.f3d, KeyJam Key Frame.stl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]
2024-03-14 Added macros and rotary encoders
2024-03-14 Latest design changes
    [KeyJam Bottom.stl, KeyJam Housing.f3d, KeyJam Max Bottom.stl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]
2024-03-17 Updated frame design
    More space for the rotary encoder and slider knob. Increased size of USB port.
    [KeyJam Bottom.stl, KeyJam Housing.f3d, KeyJam Top.stl]
2024-03-17 Made text cutout thicker
    [KeyJam Housing.f3d, KeyJam Top.stl]
2024-04-04 Updated KeyJam Max Files
    [KeyJam Max Bottom.stl, KeyJam Max Top.stl]
2026-07-02 Create Assembly Instructions.md
2026-07-03 Update Assembly Instructions.md

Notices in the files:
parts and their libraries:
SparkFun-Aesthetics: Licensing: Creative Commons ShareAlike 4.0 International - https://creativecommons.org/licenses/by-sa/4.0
